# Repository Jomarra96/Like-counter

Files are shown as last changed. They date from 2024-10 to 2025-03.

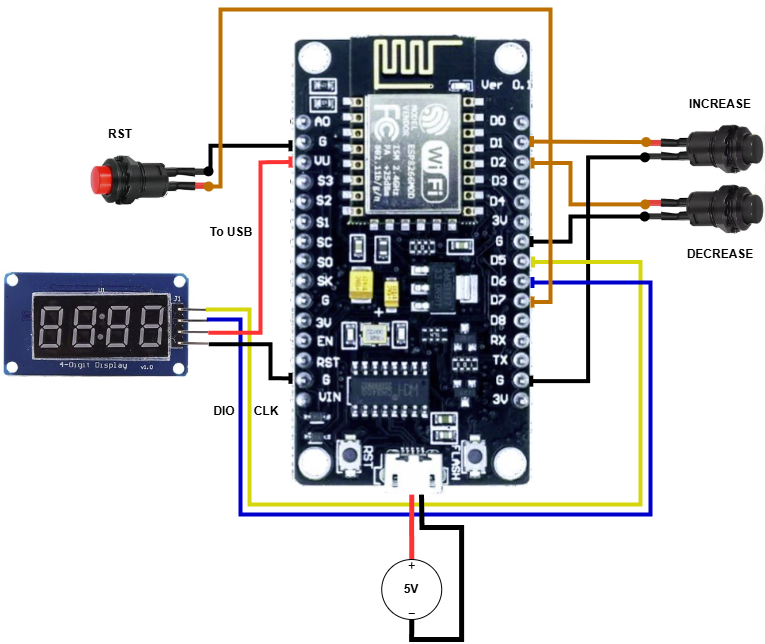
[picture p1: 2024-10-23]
Docs/Wiring/Like_counter_pinout.png

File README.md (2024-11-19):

# ESP8266 Like Box

A like counter box with buttons, a screen and permanent memory.

This device detects Like/Dislike/Rst button presses and displays the current counter on a 7-segment screen. The counter value is protected against power failures by routinely storing it on the device Flash.



2024-11-19_18h31_32

## Background

I currently work in automotive, so it was obvious I had to print the infamous [AUTOSAREEEE](https://www.reddit.com/r/embedded/comments/leq366/comment/gmiq6d0/) post and stick it on a wall by the office. Given most of my colleagues pretty much breathe AUTOSAR .arxml's, I now want to measure how fond they are of the omnipresent standard.

Could I have just gotten a commercial option? Absolutely. Do they look ugly AF? Yep. Plus, I also wanted to hack something with a little personality.

## Behavior

On Like/Dislike/RST buttons press, the internal counter updates, then gets stored in Flash and displayed on screen.
On power up, it tries reading a valid value from flash. Otherwise the counter resets.

## Replicate

Get the files in your machine, download LittleFS and TM1637Display libraries from the IDE and flash into the ESP8266 board. Follow the pinout from \Docs\Wiring. Other ESP8266 versions may not work. Use M3x10 bolts for the ESP8266 and the lid, and M2x4 for the 7-segment display.

## Features

R1 Display like count.

R2 Detect like.

R3 Detect dislike.

R4 Detect reset.

R5 Keep counter on power off.

R6 Mountable on a foam wall.

R7 Cost <20EUR.

R8 Dev time <1mo - <20h total time.

## TODO

Nothing, all done

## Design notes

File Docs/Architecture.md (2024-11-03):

# SYSTEM

## BOARD

[Lolin NodeMCU ESP8266](https://www.make-it.ca/nodemcu-details-specifications/)
4MB Flash, 64KB RAM. Noice.

HW I had laying around.
Widely supported, allows C, C++, Arduino and uPy

## SCREEN

[7 Segment display](https://www.amazon.de/dp/B07XQ2M188?ref=ppx_yo2ov_dt_b_fed_asin_title)

- Simple and cheap. TM16XX Driver included.

## BUTTONS

[Standard push button](https://www.amazon.de/gp/product/B0BXZZTH26/ref=ppx_yo_dt_b_asin_title_o01_s00?ie=UTF8&psc=1).

## CASE

3D printed.

## POWER

Wall adapter available nearby -> 5V into ESP8266 microUSB. No battery or Low power needed.

## Non Volatile Memory

Flash in ESP8266

# SW Framework

I Chose Arduino over bare C, uPy, etc. I know, I know, it's just for children, hobbyists and PHD's, but hear me out.
I haven't played with it in over 4 years, and they got version 2.0 now!

**Advantages**
- Allows for quickest implementation, without hitting its limits in this simple project.
- There are available drivers for TM16xx & LittleFS on ESP8266(!!)
	
**Disadvantages**
- No debugging in most boards
- Flashing takes >30s. Ew. Apparently they include by default a metric ton of std libs, if not all of them. Ewww.
- Huge footprint, lots of boilerplate because of the previously stated (>200KB).
- Abuse of externs/macros, hard to follow fns.
- Multiple bugs within the IDE

Now, will Arduino be worth it? Hope so, check the review file for an answer!

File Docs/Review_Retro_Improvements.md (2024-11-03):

# Review | Retro

FW took around 8h from start of design to completion. I Doubt that would have been possible with standalone C, missing the TM1637 and LittleFS libraries I had with Arduino. Arduino IDE v2 still behaves weirdly with c/h files, since most library functions have hiddend dependencies for which you need the whole .ino #include set. To modularize your code, you must create new .ino files at the same level! Annoying for everything but the smallest programs. Anyways, Arduino turned out to be a good choice for this specific project.

- Code documentation could have been easily implemented in Doxygen. FW diagram should have been done at the beginning, instead of at the end (Lazy me).

- Mechanical design took 2 iterations and a clogged hotend. For the future, ensure the modelled support pieces actually match the real ones!

- Cost was under 16EUR due to availability of parts, total time spent was around 18h, with most of it on FW and Mech design.

All requirements are met, so I consider the project a success.

# Improvements

Portability could easily be achieved with a 18650, by keeping the 7-seg display on for just a couple seconds and enabling low power on the SoC - [0.3mA without linear regulator](https://tinker.yeoman.digital/2016/05/29/running-nodemcu-on-a-battery-esp8266-low-power-consumption-revisited/). A paper display could also be used to lengthen battery life, although with a steep increase in price. (Have fun with the drivers and implementation if you want [Real low power](https://www.amazon.de/s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))

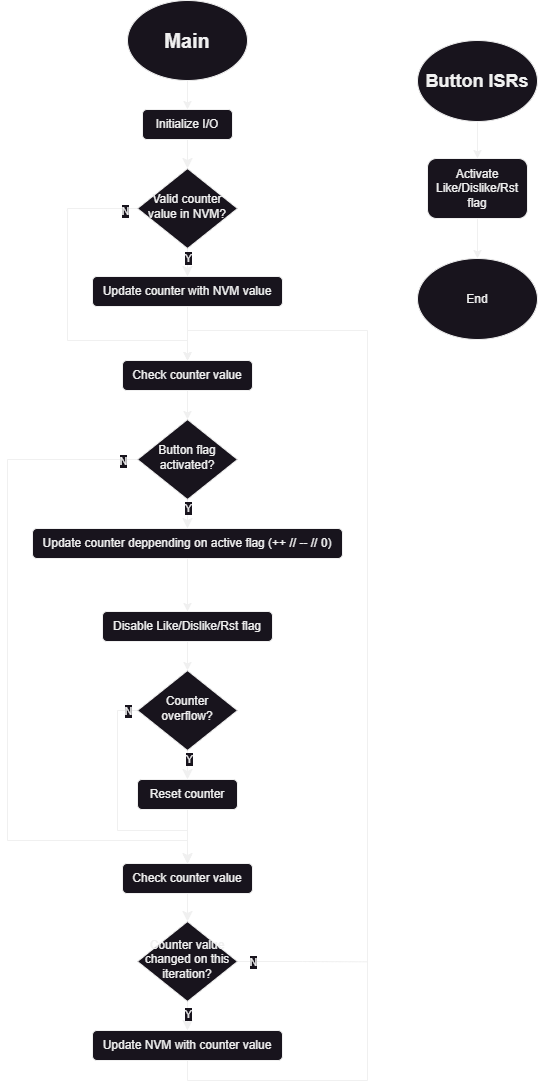
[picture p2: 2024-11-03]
Docs/FW_high_level.drawio.png

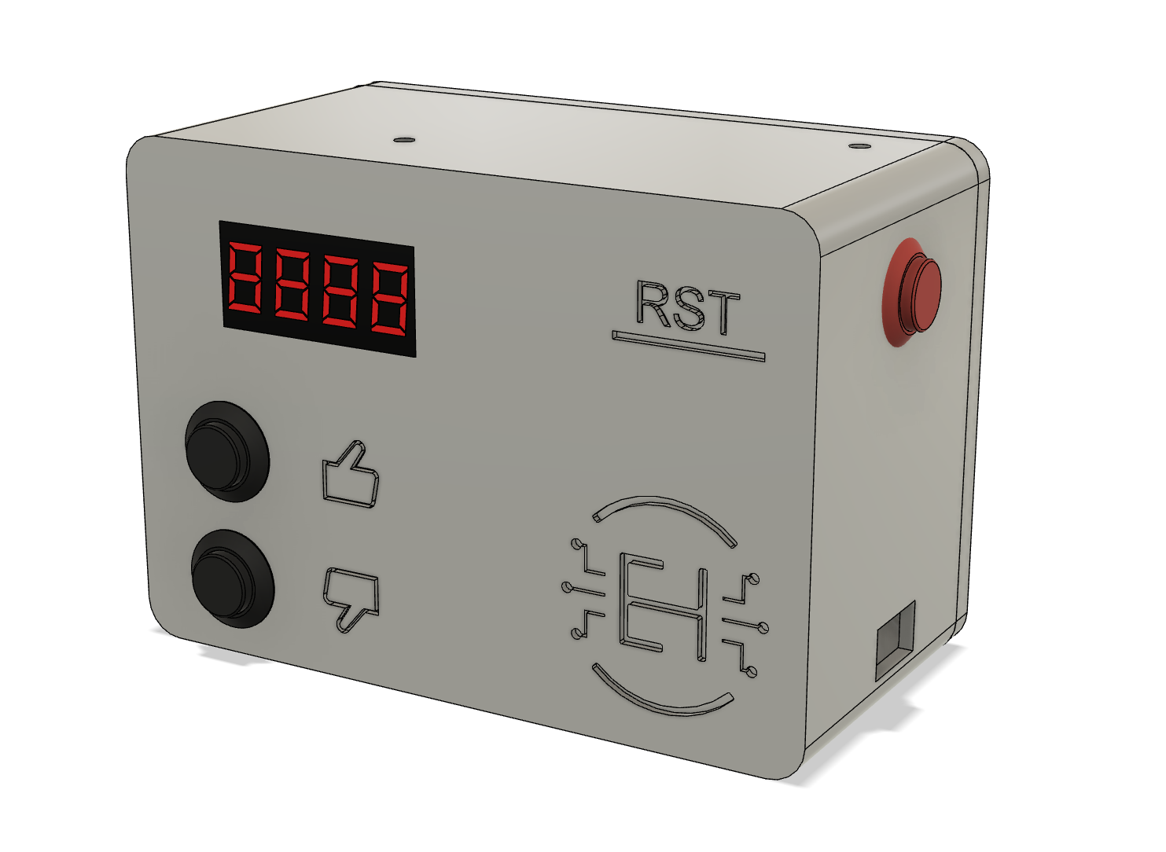
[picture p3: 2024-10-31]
Docs/CAD/Case.png

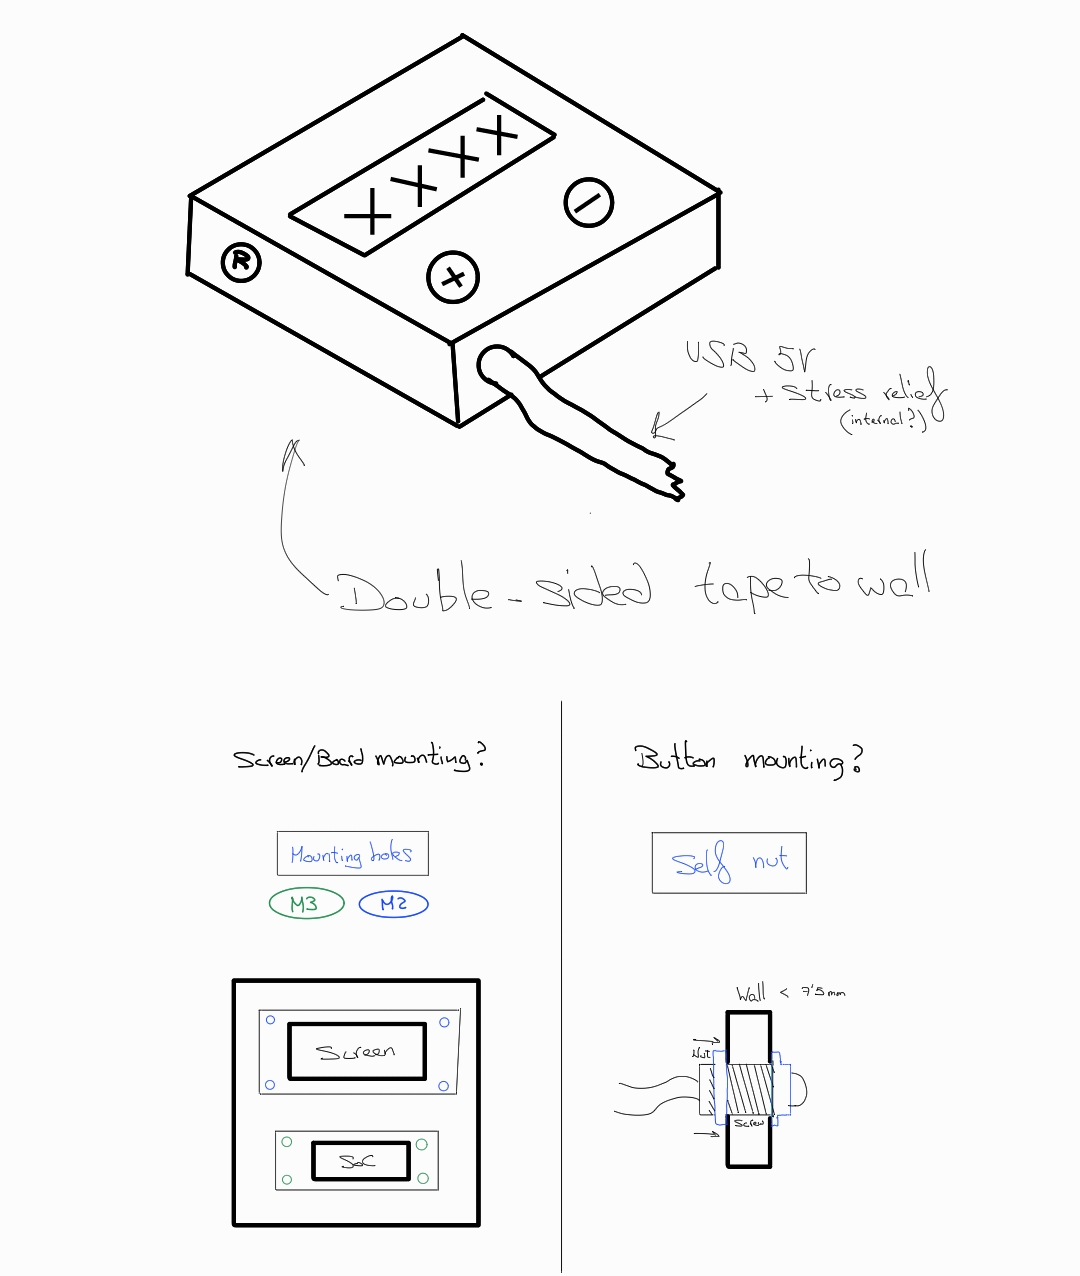
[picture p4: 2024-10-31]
Docs/CAD/Draft.jpg

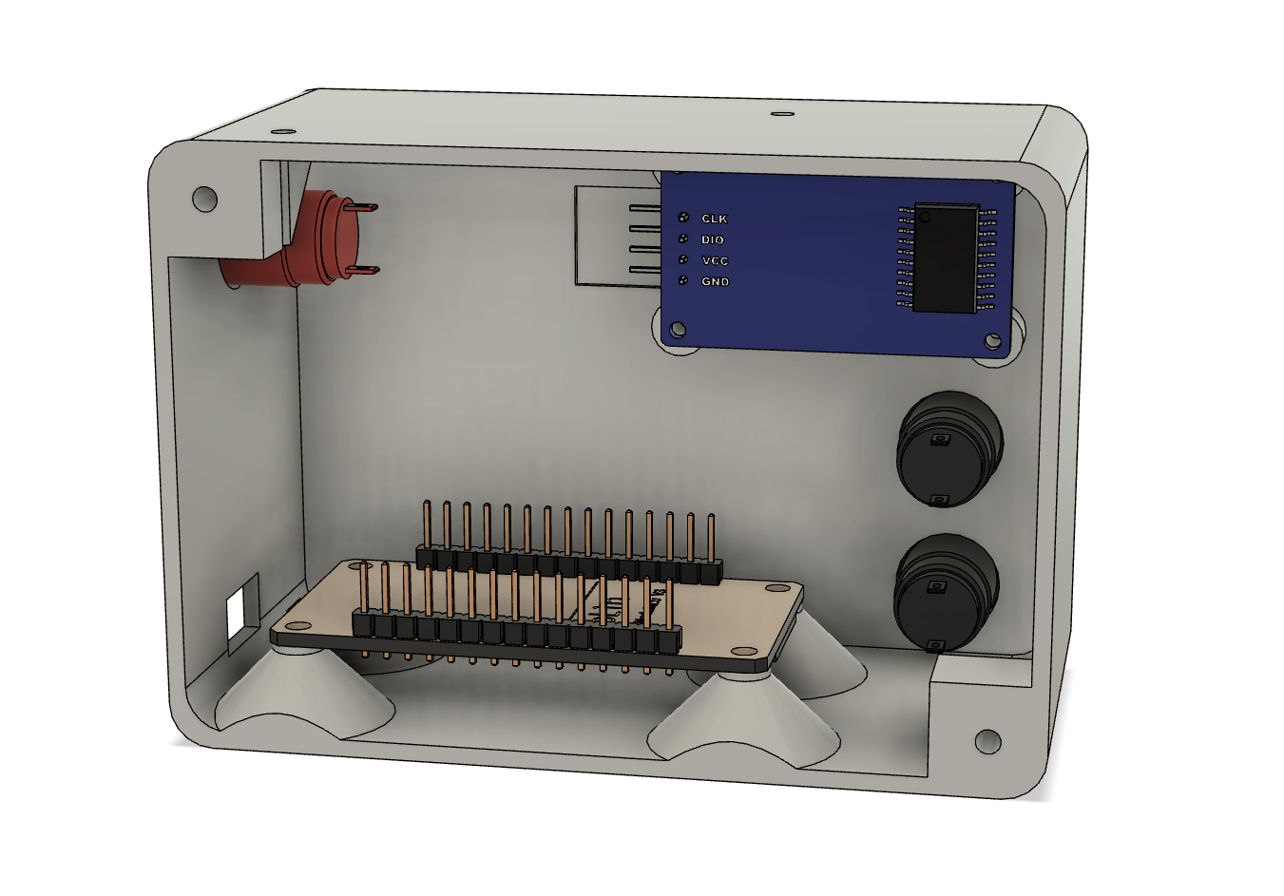
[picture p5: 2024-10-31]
Docs/CAD/Case_open.png

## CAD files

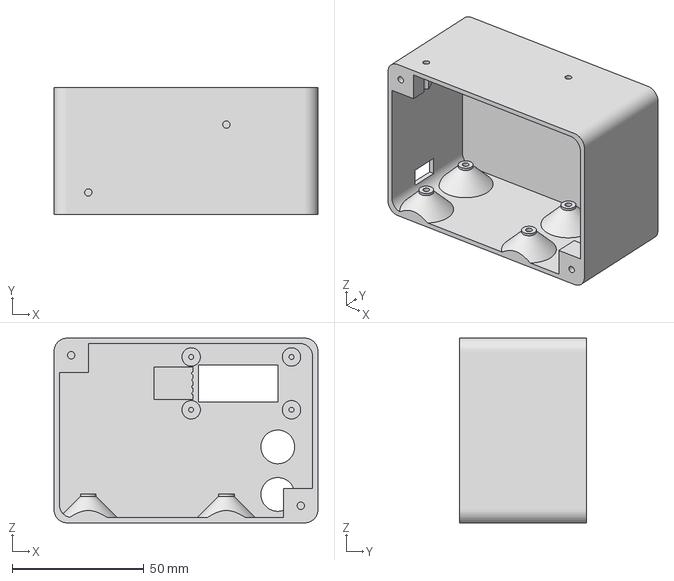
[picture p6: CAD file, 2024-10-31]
Docs/CAD/3DP/Case_body.3mf
100.0 x 48.0 x 70.0 mm

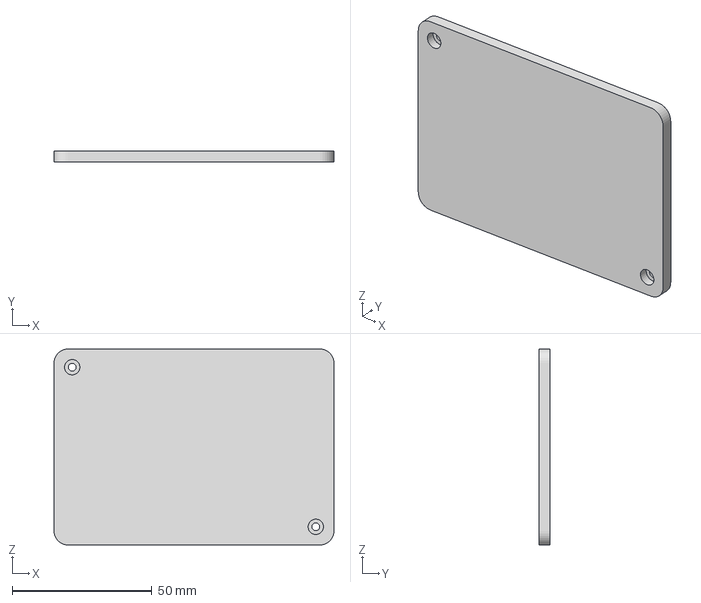
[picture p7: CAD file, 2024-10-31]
Docs/CAD/3DP/Case_lid.3mf
100.0 x 4.00 x 70.0 mm

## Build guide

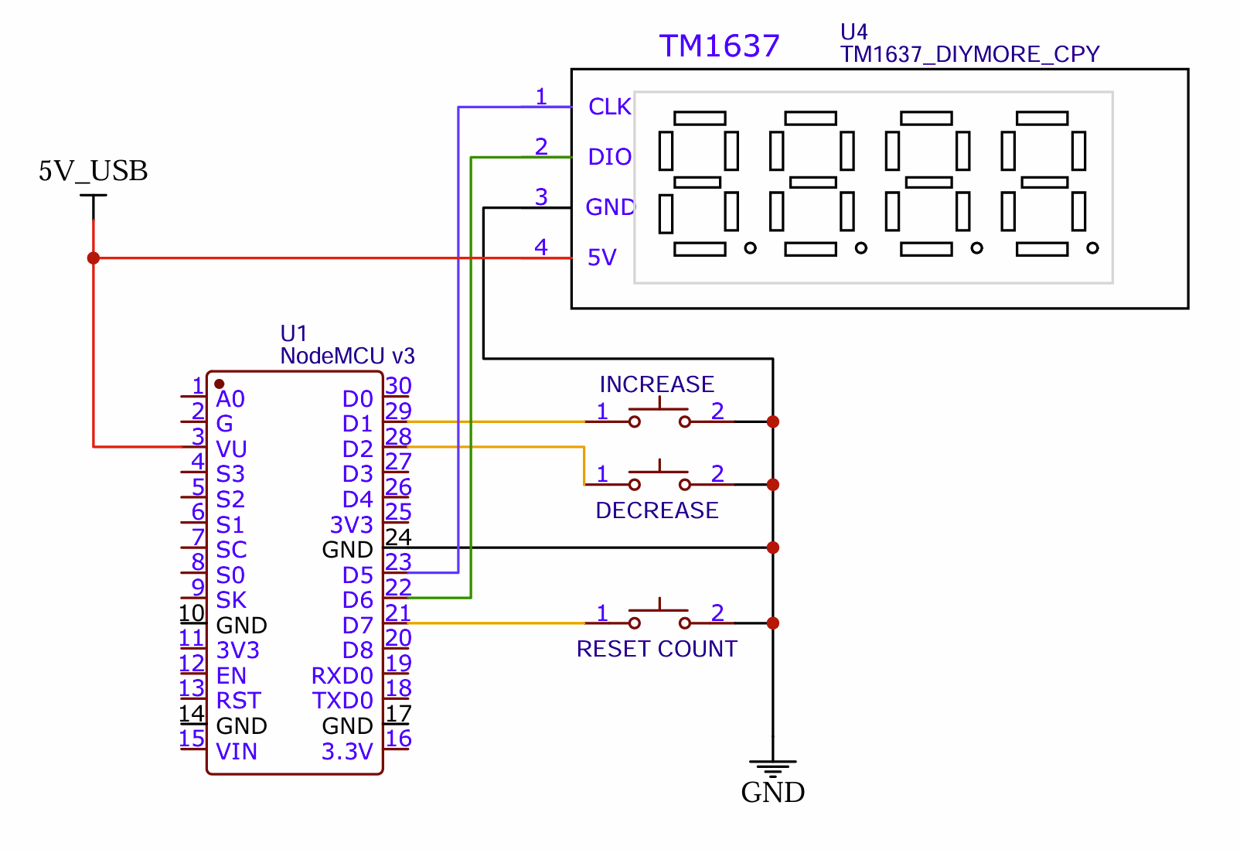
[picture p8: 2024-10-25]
Docs/Wiring/Like_counter_wiring.png

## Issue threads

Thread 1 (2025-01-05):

Counter resets after some time elapses and L/D button is pressed

Jomarra96, 2025-01-05:
When some time elapses (>10 min aprox) and like/dislike button is pressed, the counter resets. Has not happened during debugging sessions yet, when repeatedly pressing the L/D buttons.

It still happens after trying a new power source. Leave it overnight, come back and press the L/D, then it resets.

While having it at home plugged into a power brick and connecting other device to the same brick, it increases the counter. Pressing the like/dislike buttons before has no effect on the change. This is also inconsistent.

Cues may indicate power unstability. Could try adding some caps in the power rail or using a perfboard, instead of the current spider/dupont setup. Could also use an Oscope to monitor power supply ripple/noise.

Jomarra96, 2025-03-11:
1- Check with logic analyzer/oscope if RST button couples when like/dislike are pressed after some time.

Closed 2025-03-17.

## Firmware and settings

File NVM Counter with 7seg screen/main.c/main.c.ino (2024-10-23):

#include <Arduino.h>
#include <LittleFS.h>
#include <TM1637Display.h>

void setup() {
  // Init Serial Communication
  Serial.begin(115200);
  Serial.println("Start");

  setupLed();
  setupButtons();
  setupISR();
  setupNvm(); // Init LittleFS
  setupLikeCounter();
  setup_display();
}

void loop() {
  static int16_t like_count = 0;
  static int16_t temp_like_count = 0;

  getCounter(&like_count);
  temp_like_count = like_count;

  handleButtonPresses();
  handleCounterRollback();
  handleCounterUpdate();

  getCounter(&like_count);
  if(temp_like_count != like_count)
  {
    update_display();
  }
}

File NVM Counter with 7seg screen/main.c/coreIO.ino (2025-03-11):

const uint8_t D1_PIN = 5;        // D1 (GPIO5)
const uint8_t D2_PIN = 4;        // D2 (GPIO4)
const uint8_t D7_PIN = 13;        // D7 (GPIO13)
const uint16_t debounce_ms = 1000;  // ESP8266/32 have issues with falling/rising edges! (https://github.com/espressif/arduino-esp32/issues/1111) 

// Variables for debounce and detection states
volatile uint32_t like_update_time = 0;
volatile uint32_t dislike_update_time = 0;
volatile uint32_t rst_update_time = 0;
volatile bool like_detected = false;
volatile bool dislike_detected = false;
volatile bool reset_counter_detected = false;

const uint8_t LED_PIN = 2;       // LED pin

void setupButtons(){
    // Set up buttons as inputs with pull-up resistors
    pinMode(D1_PIN, INPUT_PULLUP);
    pinMode(D2_PIN, INPUT_PULLUP);
    pinMode(D7_PIN, INPUT_PULLUP);    
}

void setupISR(){
  // Attach interrupts for button presses. Edge type doesn't matter. ESP32 treats both as the same.
  attachInterrupt(digitalPinToInterrupt(D1_PIN), ISR_like_press, FALLING);
  attachInterrupt(digitalPinToInterrupt(D2_PIN), ISR_dislike_press, FALLING);
  attachInterrupt(digitalPinToInterrupt(D7_PIN), ISR_reset_counter, FALLING);
}

void handleButtonPresses() {
  if (like_detected) {
    Serial.println("Like");
    like_detected = false;
    increaseLikeCounter();
  }

  if (dislike_detected) {
    Serial.println("Dislike");
    dislike_detected = false;
    decreaseLikeCounter();
  }

  if (reset_counter_detected) {
    Serial.println("Counter reset");
    reset_counter_detected = false;
    resetCounter();
  }
}

// ISRs
IRAM_ATTR static void ISR_like_press() {
  // Debouncing for like button press
  if (like_update_time > millis()) {
    like_update_time = 0;
  }

  if ((millis() - like_update_time) > debounce_ms) {  //Check for debounce time
    like_detected = true; 
    like_update_time = millis();
  }
}

IRAM_ATTR static void ISR_dislike_press() {
  // Debouncing for dislike button press
  if (dislike_update_time > millis()) {
    dislike_update_time = 0;
  }

  if ((millis() - dislike_update_time) > debounce_ms) { //Check for debounce time
    dislike_detected = true;
    dislike_update_time = millis();
  }
}

IRAM_ATTR static void ISR_reset_counter() {
  // Debouncing for dislike button press
  if (rst_update_time > millis()) {
    rst_update_time = 0;
  }

  if ((millis() - rst_update_time) > debounce_ms) { //Check for debounce time
    reset_counter_detected = true;
    rst_update_time = millis();
  }
}

void setupLed() {
    // Set up LED pin as output
    pinMode(LED_PIN, OUTPUT);
}

void handleHeartbeat() {
#if (1)  
  digitalWrite(LED_PIN, LOW);
  delay(500);
  digitalWrite(LED_PIN, HIGH);
  delay(500);
#endif
}

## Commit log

2024-10-22 [ADD] Initial commit
    [ADD] Implement button ISR
2024-10-23 [ADD] Implement reset counter
    [coreIO.ino, nvm.ino]
2024-10-25 [ADD] Include case drafts
2024-10-31 [ADD] Include CAD files
    [MOD] Change directory structure
    [Case_body.3mf, Case_lid.3mf]
2024-11-06 [MOD] Include bolt information in Readme
2025-03-11 [FIX] Correct button edge trigger detection
    Doesn't really matter since ESP32 treats both RISING and FALLING as the same, but w/e
    [coreIO.ino]
2025-03-17 [MOD] Turn LED off
    [MOD] Lower display brightness to minimum
    [MOD] Increase button responsiveness to 500ms
